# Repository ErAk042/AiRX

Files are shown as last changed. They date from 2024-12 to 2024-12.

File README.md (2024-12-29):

# AiRX
AiRX is a modularized fully-analog superheterodyne AM radio receiver for the aviation band (117-140MHz). The system consists of an input filter + LNA, a LNA + mixer stege for converting the band to 7-30MHz range, a Xtal oscillator at 110MHz as the first LO, and a LA1267 based AM radio to demodulate the signal with an additional LM386 amp for driving speakers.

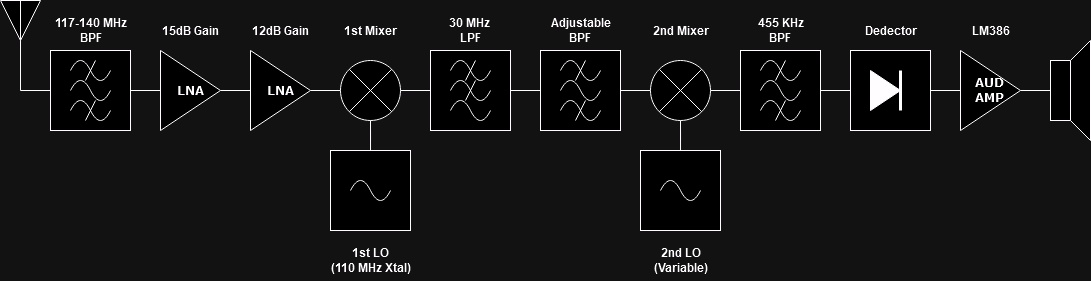
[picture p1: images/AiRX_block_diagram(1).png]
Block diagram of the overall system


## Input Stage
The input stage is a 9th order bandpass filter (117-40MHz passband) made using high-q aircore inductors. Right after the filter, there is a LNA block made using the BFP196W RF transistor. Bias network is made using a BC807 PNP transistor. The circuit aims to provide a 15mA current flow over the RF transistor. The overall gain of the LNA block here is around 15dB. The final PCB ins enclosed in a phosphorus-bronze enclosure and the power supply cable is filtered by going through a ferride bead to minimize the RF interference by nearby electronics.

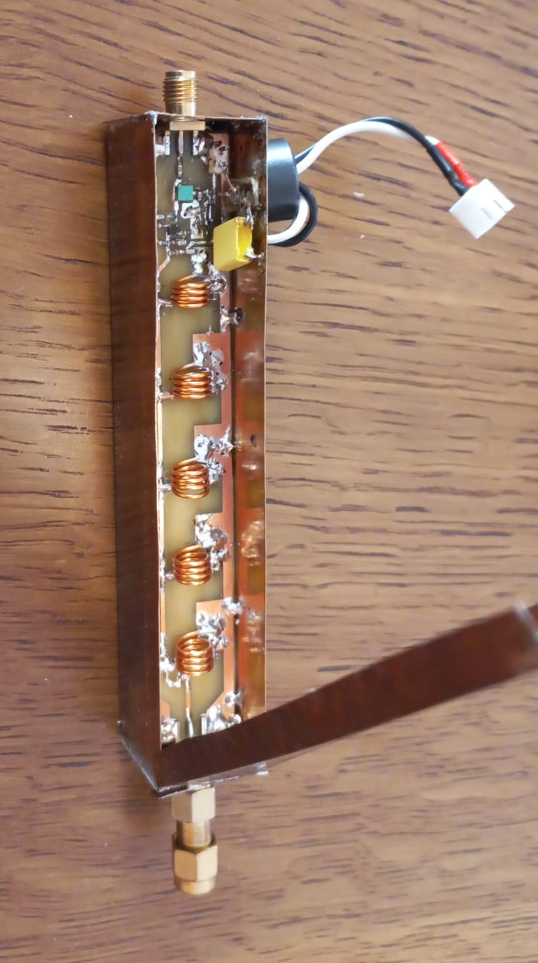
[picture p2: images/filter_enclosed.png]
The input stage inside it's enclosure. The sides of the lid are bent frequently with small cuts to improve the seal.

The input stage inside it's enclosure. The sides of the lid are bent frequently with small cuts to improve the seal.

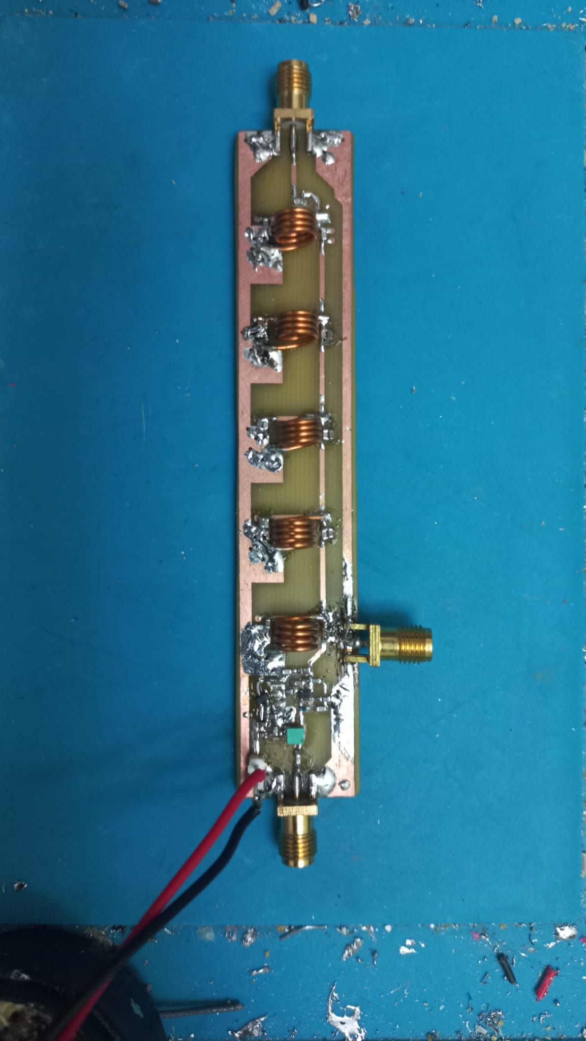
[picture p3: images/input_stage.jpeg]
The populated PCB of the input stage. The 3rd SMA connector on the long edge was a temporary test point between the filter and LNA.

The populated PCB of the input stage. The 3rd SMA connector on the long edge was a temporary test point between the filter and LNA.

## 110MHz Oscillator
A 22MHz crystal is used in 5th overtone to achieve 110MHz 1st LO frequency. There is a filter at the output of the oscillator buffer to filter out any potential harmonics/noise.

## Mixer Stage
The mixer used to bring the band down to the HF range is a SA612 double balanced mixer. At the RF input there is another LNA based on the same BFP196W transistor. It's the same circuit as the input stage LNA, only difference being that the current going through the transistor is roughly 1.4x higher. After that, the signal is fed to the 612's RF input with a 4:1 balun. Since the input impedance of the 612 is around 2kOhms, this balun allows the output of the transistor to be matched better than a straight transmission line. Since the band used is pretty wide, a matching network was not a practical solution in this case.
The 110MHz is directly fed into the base of the internal oscillator transistor of the 612.
At the output, there is a LPF with a cutoff frequency of 30MHz. This both filters out the images and reduces the overall noise level of the system.

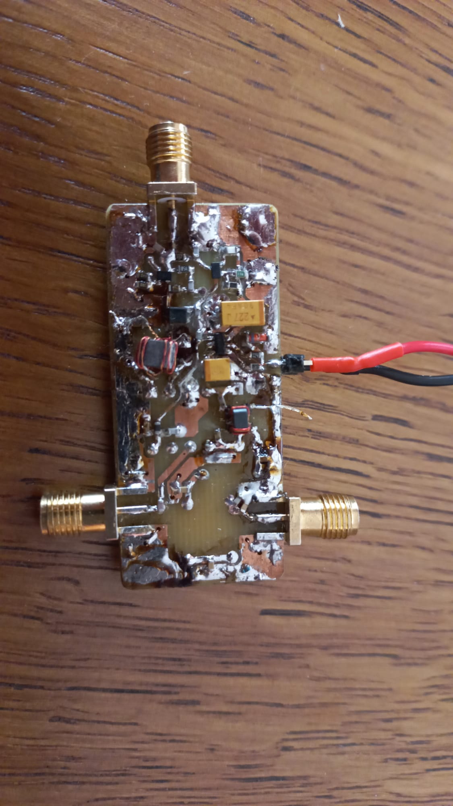
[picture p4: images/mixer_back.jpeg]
The back side of the mixer module.

The back side of the mixer module.

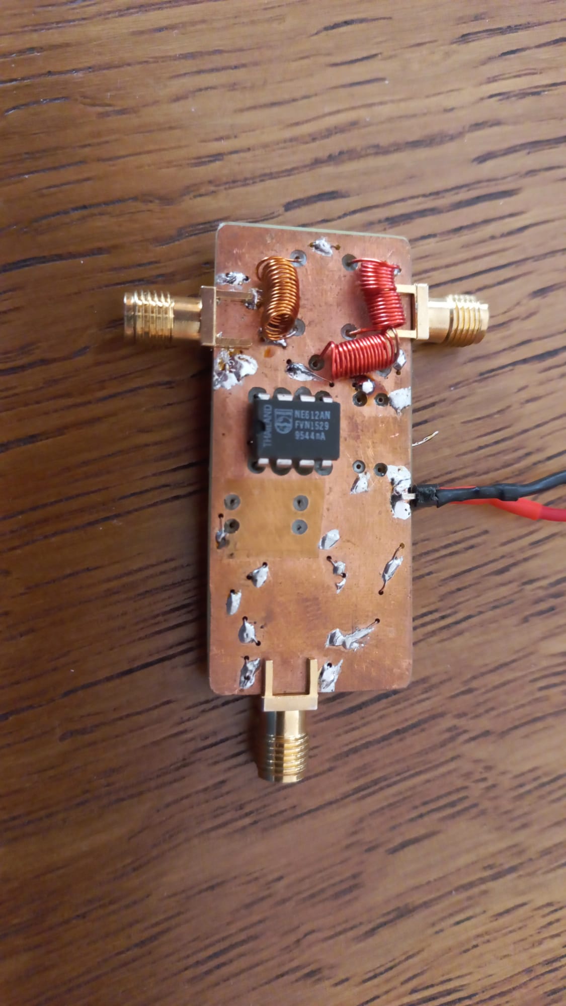
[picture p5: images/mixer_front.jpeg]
The front side of the mixer module.

The front side of the mixer module.

## AM Demodulator
The signals from the mixer module is directly fed to the input of this module. This is a superheterodyne shortwave radio based on the LA1267 chip by Sanyo. At the input, there is a variable band selective filter. The variable capacitor determines the band, as well as the LO frequency of the radio. The audio output is then fed into a LM386 amplifier. The outout can be directly used to drive medium-sized speakers. For the sake of conveniency, I later used a Si5351 frequency sythesizer controlled by an Arduino as the LO to precisely select the band that I wanted to listen to. I was able to account for the slight offset(24KHz) of the 110MHz oscillator with this solution, while achieving precise frequency control. This was a huge improvement since the bandwith is limited to 6-8KHz, which makes it hard to manually adjust the frequency using the variable capacitor without any pulley system. 

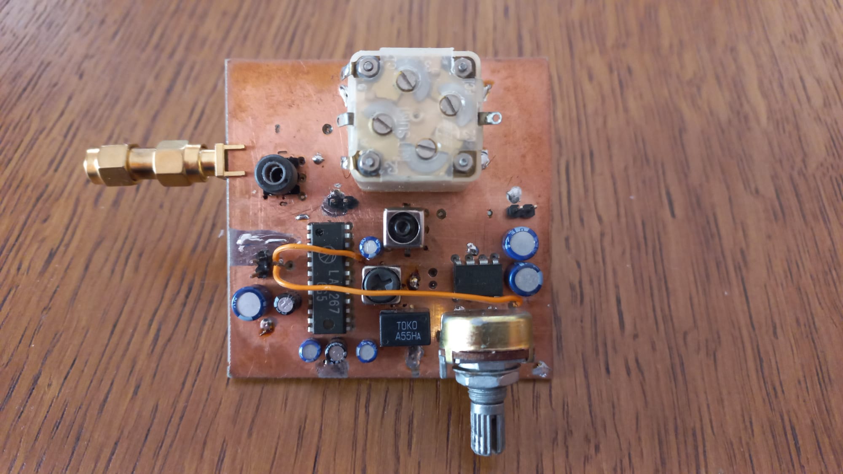
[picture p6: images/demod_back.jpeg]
The back side of the demodulator module.

The back side of the demodulator module.

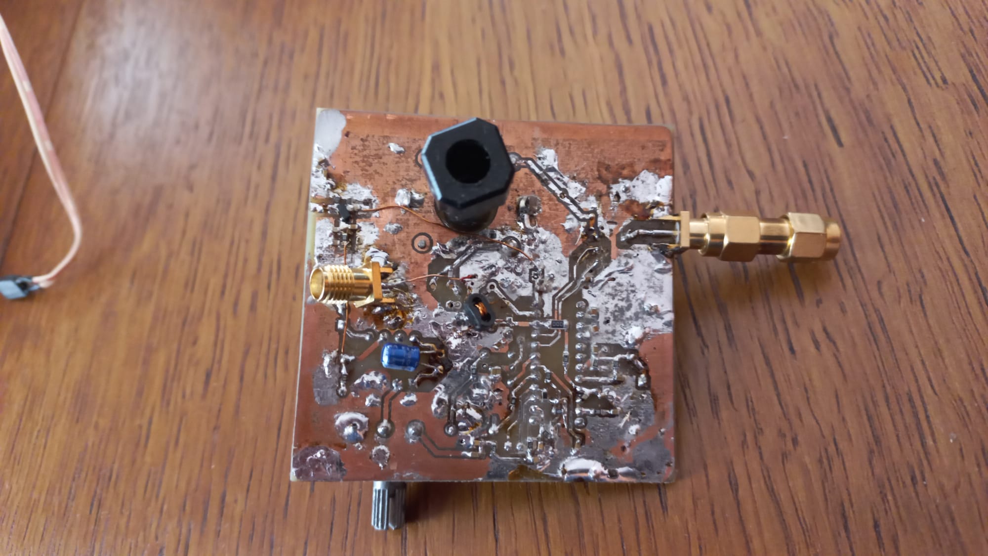
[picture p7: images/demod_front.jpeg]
The front side of the demodulator module.

The front side of the demodulator module.

## Planned future updates
I'm palnning on using a variable frequency filter for the input stage, which shoould help with the overall sensetivity of the system by limiting the witdh of the band admitted. Also, I want to use a more powerful mixer for the fisr mixer stage, so the dynamic range of the system can be improved. An AGC system is also within my plans.

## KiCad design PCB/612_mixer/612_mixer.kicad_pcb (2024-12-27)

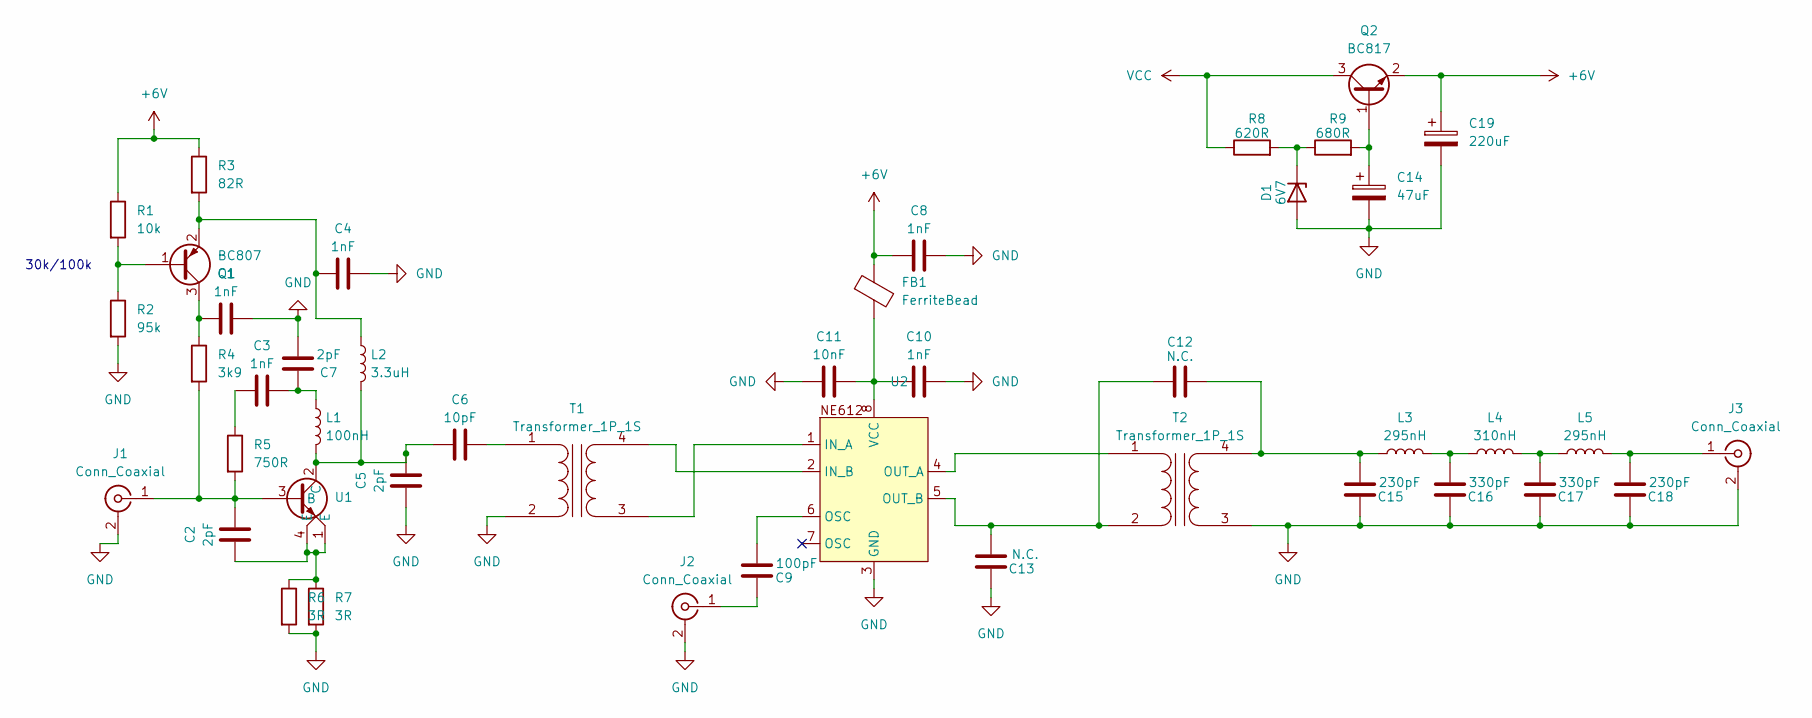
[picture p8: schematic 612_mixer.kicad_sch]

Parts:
C1, C3, C4, C8, C10: 1nF; C_0603_1608Metric
C2, C5, C7: 2pF; C_0603_1608Metric
C6: 10pF; C_0603_1608Metric
C9: 100pF; C_0603_1608Metric
C11: 10nF; C_0603_1608Metric
C12, C13: N.C.; C_0603_1608Metric
C14: 47uF; CP_EIA-3528-21_Kemet-B
C15, C18: 230pF; C_0603_1608Metric
C16, C17: 330pF; C_0603_1608Metric
C19: 220uF; CP_EIA-6032-28_Kemet-C
D1: 6V7; L_1206_3216Metric
FB1: FerriteBead; C_0603_1608Metric
J1, J2, J3: Conn_Coaxial; SMA_Samtec_SMA-J-P-H-ST-EM1_EdgeMount
L1: 100nH; L_0402_1005Metric
L2: 3.3uH; L_1008_2520Metric
L3, L5: 295nH; R_Axial_DIN0207_L6.3mm_D2.5mm_P7.62mm_Horizontal
L4: 310nH; R_Axial_DIN0207_L6.3mm_D2.5mm_P7.62mm_Horizontal
Q1: BC807; SOT-323_SC-70
Q2: BC817; SOT-23
R1: 10k; R_0603_1608Metric
R2: 95k; R_0603_1608Metric
R3: 82R; R_0603_1608Metric
R4: 3k9; R_0603_1608Metric
R5: 750R; R_0603_1608Metric
R6, R7: 3R; R_0603_1608Metric
R8: 620R; R_0603_1608Metric
R9: 680R; R_0603_1608Metric
T1, T2: Transformer_1P_1S; SW_DIP_SPSTx02_Slide_6.7x6.64mm_W7.62mm_P2.54mm_LowProfile
U1: SOT343_Transistor
U2: DIP-8_W7.62mm

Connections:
+6V: C8.2, C19.1, FB1.1, Q2.2 (E), R1.1, R3.1
GND: C1.1, C4.1, C5.2, C7.2, C8.1, C10.1, C11.1, C13.1, C14.2, C15.1, C16.1, C17.1, C18.1, C19.2, D1.2 (A), J1.2 (Ext), J2.2 (Ext), J3.2 (Ext), R2.2, R6.2, R7.2, T1.2 (AB), T2.3 (SA), U2.3 (GND)
unnamed: C2.2, R6.1, R7.1, U1.1 (E), U1.4 (E)
unnamed: C3.1, C7.1, L1.1
unnamed: C3.2, R5.1
unnamed: C9.2, U2.6 (OSC)
unnamed: C16.2, L3.2, L4.1
unnamed: C17.2, L4.2, L5.1
unnamed: D1.1 (K), R8.2, R9.1
unnamed: C2.1, J1.1 (In), R4.2, R5.2, U1.3 (B)
unnamed: C9.1, J2.1 (In)
unnamed: C18.2, J3.1 (In), L5.2
unnamed: Q1.1 (B), R1.2, R2.1
unnamed: C1.2, Q1.3 (C), R4.1
unnamed: C4.2, L2.1, Q1.2 (E), R3.2
unnamed: C14.1, Q2.1 (B), R9.2
unnamed: C6.1, T1.1 (AA)
unnamed: T1.3 (SA), U2.1 (IN_A)
unnamed: T1.4 (SB), U2.2 (IN_B)
unnamed: T2.1 (AA), U2.4 (OUT_A)
unnamed: C12.2, C13.2, T2.2 (AB), U2.5 (OUT_B)
unnamed: C12.1, C15.2, L3.1, T2.4 (SB)
unnamed: C5.1, C6.2, L1.2, L2.2, U1.2 (C)
unnamed: C10.2, C11.2, FB1.2, U2.8 (VCC)
VCC: Q2.3 (C), R8.1

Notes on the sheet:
30k/100k

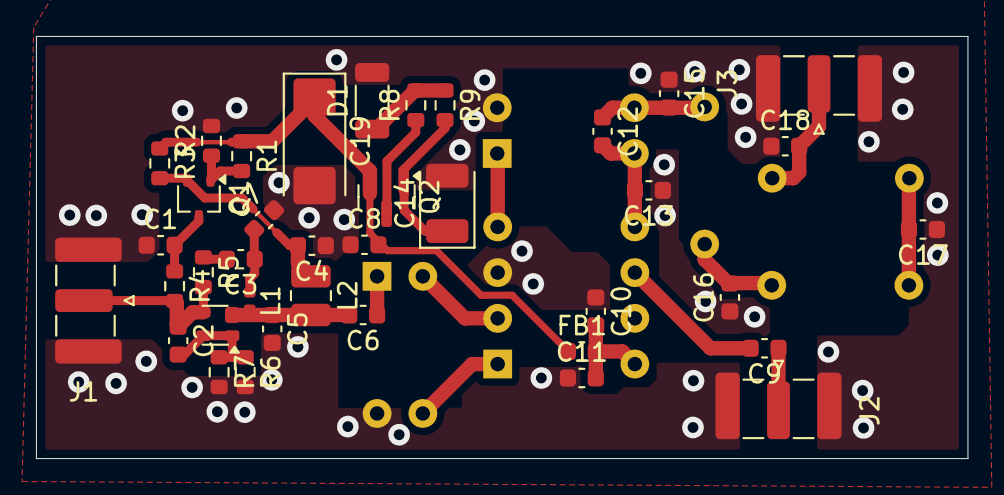
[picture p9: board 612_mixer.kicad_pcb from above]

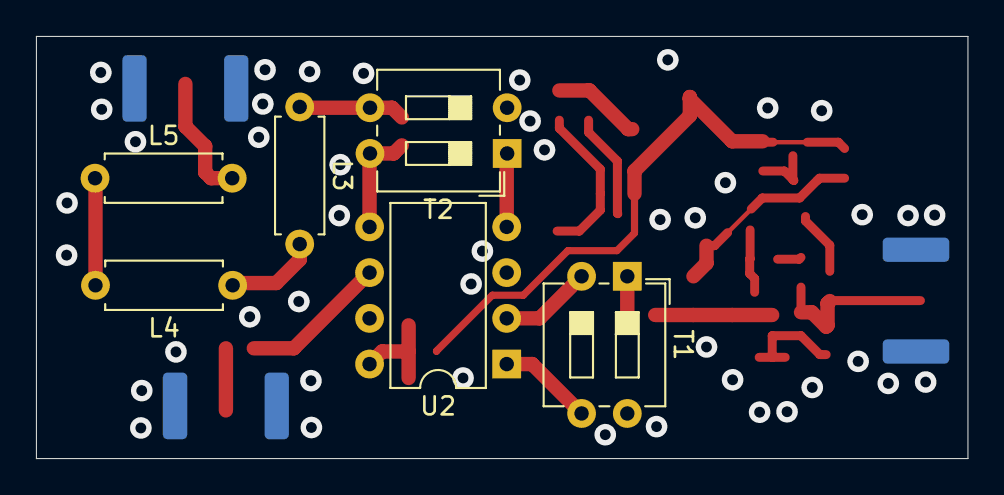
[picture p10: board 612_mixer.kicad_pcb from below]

Board: 2 copper layers, 51.8 x 23.5 mm, 44 parts (6 on the bottom side), 25 nets.

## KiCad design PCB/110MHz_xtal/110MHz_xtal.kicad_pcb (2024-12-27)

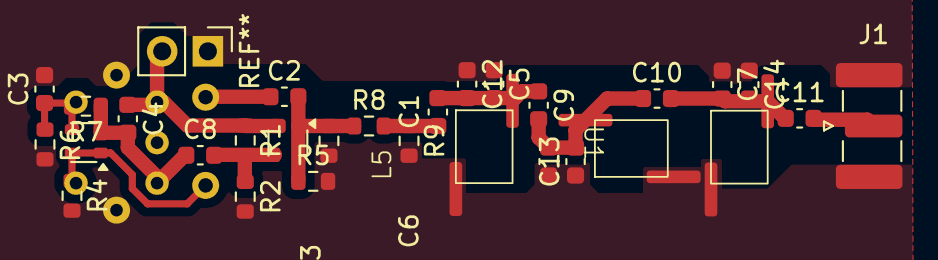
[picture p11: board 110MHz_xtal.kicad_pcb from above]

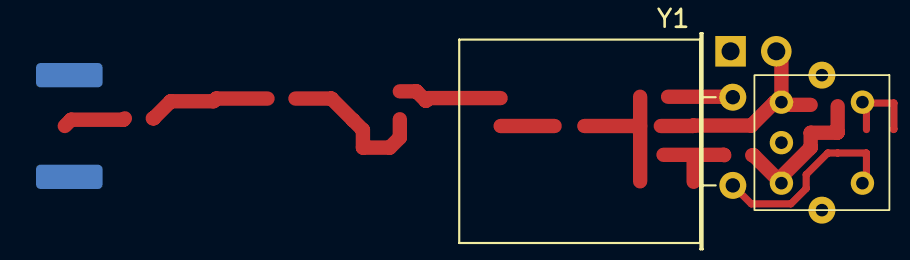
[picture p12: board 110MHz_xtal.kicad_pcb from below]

Board: 2 copper layers, 31 parts (2 on the bottom side), 13 nets.

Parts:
C1, C11: 2.9pF; C_0603_1608Metric
C2: 15pF; C_0603_1608Metric
C3, C4, C8: 1nF; C_0603_1608Metric
C5, C12: 17.67pF; C_0603_1608Metric
C6, C13: 20.12pF; C_0603_1608Metric
C7, C14: 17.62pF; C_0603_1608Metric
C9, C10: 0.5pF; C_0603_1608Metric
J1: Conn_Coaxial_Small; SMA_Samtec_SMA-J-P-H-ST-EM1_EdgeMount
L1: Inductor_IF
L4, L5, L6: L; inductor_small
R1: 51k; R_0603_1608Metric
R2, R6: N.C.; R_0603_1608Metric
R3, R8, R9: 15k; R_0603_1608Metric
R4: 330R; R_0603_1608Metric
R5: 150R; R_0603_1608Metric
R7: 470k; R_0603_1608Metric
U1, U2: SOT343_Transistor
Y1: Crystal; Crystal_HC49-U_Horizontal

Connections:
+BATT: C4.1, L1.1, R1.1, U1.2 (C)
GND: C3.2, C5.1, C6.1, C7.1, C12.1, C13.1, C14.1, J1.2 (Ext), L1.6, L4.1, L5.1, L6.1, R2.2, R3.2, R4.2, R5.2, R6.2, R9.2
unnamed: C1.1, R8.2, R9.1
unnamed: C1.2, C5.2, C9.1, C12.2, L4.2
unnamed: C2.1, Y1.1
unnamed: C2.2, R3.1, R5.1, R8.1, U1.1 (E), U1.4 (E)
unnamed: C6.2, C9.2, C10.1, C13.2, L5.2
unnamed: C7.2, C10.2, C11.1, C14.2, L6.2
unnamed: C11.2, J1.1 (In)
unnamed: L1.4, R4.1, U2.1 (E), U2.4 (E), Y1.2
unnamed: C8.2, R1.2, R2.1, U1.3 (B)
unnamed: C3.1, L1.5, R6.1, R7.2, U2.3 (B)
unnamed: C4.2, C8.1, L1.3, R7.1, U2.2 (C)

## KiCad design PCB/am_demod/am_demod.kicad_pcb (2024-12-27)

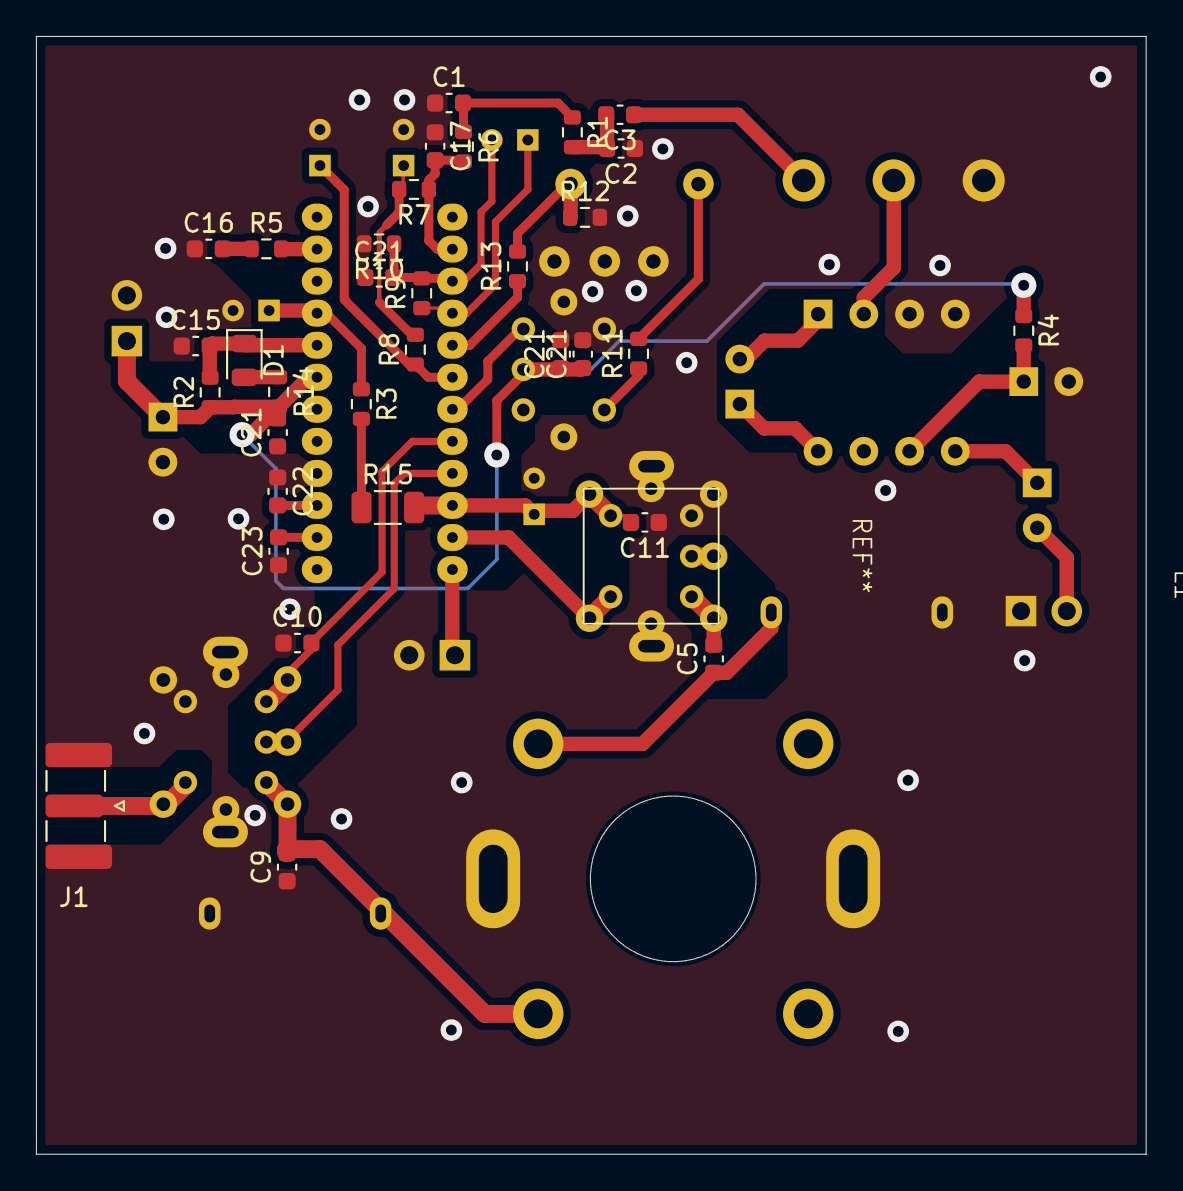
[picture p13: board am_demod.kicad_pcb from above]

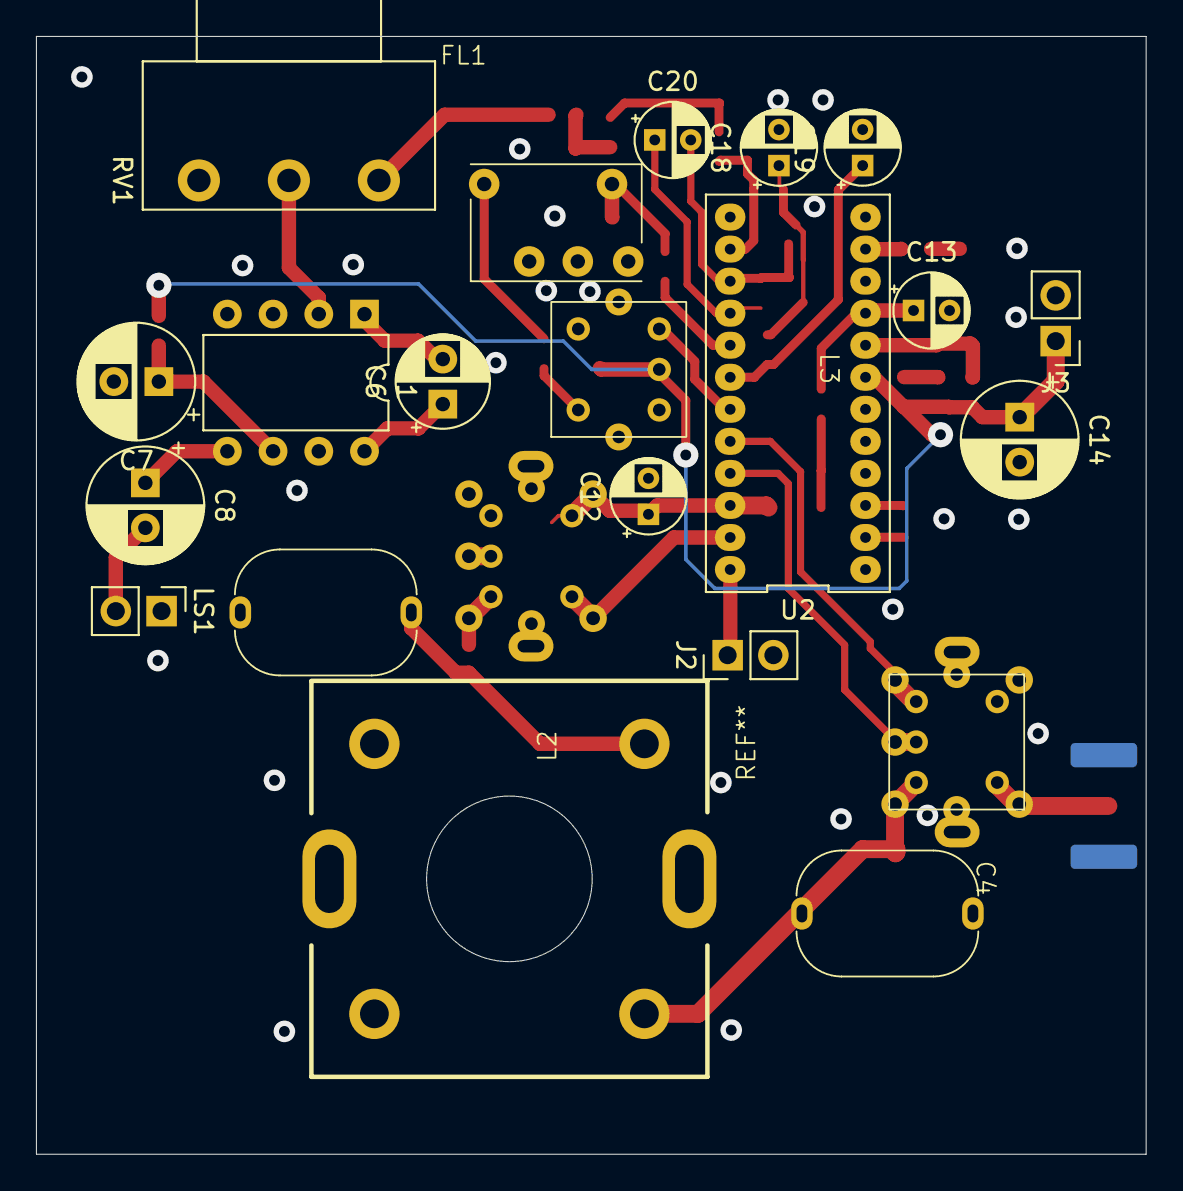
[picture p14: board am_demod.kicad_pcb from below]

Board: 2 copper layers, 61.7 x 62.1 mm, 55 parts (22 on the bottom side), 38 nets.

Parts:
C1: 10nF; C_0603_1608Metric
C2: 3.3nF; C_0603_1608Metric
C3: 100nF; C_0603_1608Metric
C4: Variable_Capacitance
C5: 4.7nF; C_0603_1608Metric
C6: 10uF; CP_Radial_D5.0mm_P2.50mm
C7: 100uF; CP_Radial_D6.3mm_P2.50mm
C8: 47uF; CP_Radial_D6.3mm_P2.50mm
C9: 15pF; C_0603_1608Metric
C10, C11, C15, C16, C22, C23: 47n; C_0603_1608Metric
C12, C13, C20: 10µF; CP_Radial_D4.0mm_P2.00mm
C14: 100µF; CP_Radial_D6.3mm_P2.50mm
C17: 15n; C_0603_1608Metric
C18: 3,3µF; CP_Radial_D4.0mm_P2.00mm
C19: 4,7µF; CP_Radial_D4.0mm_P2.00mm
C21, C21#2, C21#3, C21#4: 22nF; C_0603_1608Metric
C24, C25: C_Trim; cap_trim
D1: LED; LED_0805_2012Metric
FL1: A55Ha
J1: Conn_Coaxial; SMA_Samtec_SMA-J-P-H-ST-EM1_EdgeMount
J2, J3: Conn_01x02_Pin; PinHeader_1x02_P2.54mm_Vertical
L1, L2: if_inductor_am
L3: Inductor_IF
LS1: Speaker; PinHeader_1x02_P2.54mm_Vertical
R1: 2K7; R_0603_1608Metric
R2: 1k; R_0603_1608Metric
R3, R5, R14: 15k; R_0603_1608Metric
R4: 10R; R_0603_1608Metric
R6: 3k3; R_0603_1608Metric
R7, R8: 10k; R_0603_1608Metric
R9: 5k1; R_0603_1608Metric
R10: 12k; R_0603_1608Metric
R11, R12, R13: 0R; R_0603_1608Metric
R15: 0R; R_1206_3216Metric
RV1: 10K; Potentiometer_Piher_PC-16_Single_Horizontal
U1: LM386; DIP-8_W7.62mm
U2: DIP-24_296_ELL

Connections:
/AUD: C1.2, R1.1, R6.1
GND: C1.1, C2.1, C4.2, C4.5, C7.2, C9.1, C10.1, C11.1, C12.2, C13.2, C14.2, C15.1, C16.1, C17.1, C18.2, C19.2, C21.2, C21#2.1, C21#3.1, C21#4.2, C22.1, C23.1, C24.1, C25.1, FL1.3, FL1.4 (GND), FL1.5, J1.2 (Ext), J2.2, J3.2, L1.3, L1.6, L1.7, L2.5, L2.6, L2.7, L3.4, L3.6, LS1.1, R10.2, R12.2, RV1.3, U1.3 (+), U1.4 (GND), U2.4 (GND)
unnamed: C2.2, C3.2, R1.2
unnamed: C3.1, RV1.1
unnamed: C5.2, L1.1
unnamed: C6.1, U1.8 (GAIN)
unnamed: C6.2, U1.1 (GAIN)
unnamed: C8.1, U1.5
unnamed: C8.2, LS1.2
unnamed: C10.2, L2.3, U2.20 (AM_IN)
unnamed: C16.2, R5.1
unnamed: C18.1, R7.2, R8.2
unnamed: C20.1, R9.1, U2.16
unnamed: C20.2, C21#3.2, R9.2, R10.1, U2.15
unnamed: C22.2, U2.3
unnamed: C23.2, U2.2
unnamed: C4.4, C9.2, C24.2, L2.1
unnamed: C4.6, C5.1, C25.2
unnamed: D1.2 (A), R14.1
unnamed: C15.2, D1.1 (K), R2.2, U2.8 (LED_IN)
unnamed: FL1.1 (IN), R11.2
unnamed: FL1.2 (OUT), R12.1, R13.2
unnamed: J1.1 (In), L2.4
unnamed: J2.1, U2.24 (OSC_BUF)
unnamed: L2.2, U2.21 (AM_IN)
unnamed: L3.5, R11.1
unnamed: R3.2, R15.1
unnamed: RV1.2, U1.2 (-)
unnamed: C7.1, R4.2, U1.6 (V+)
unnamed: C19.1, R8.1, U2.18 (AGC)
unnamed: R13.1, U2.17 (AIF_IN)
unnamed: L3.3, U2.19 (AMIX_OUT)
unnamed: L1.4, U2.23 (AM_OSC)
unnamed: C17.2, R6.2, R7.1, U2.14 (AM_OUT)
unnamed: C11.2, C12.1, L1.5, R15.2, U2.22 (REG_OUT)
unnamed: C13.1, R3.1, U2.9 (S_CRV)
unnamed: R5.2, U2.11 (S_MET)
VCC: C14.1, C21.1, C21#2.2, C21#4.1, J3.1, L3.2, R2.1, R4.1, R14.2, U2.7 (VCC)

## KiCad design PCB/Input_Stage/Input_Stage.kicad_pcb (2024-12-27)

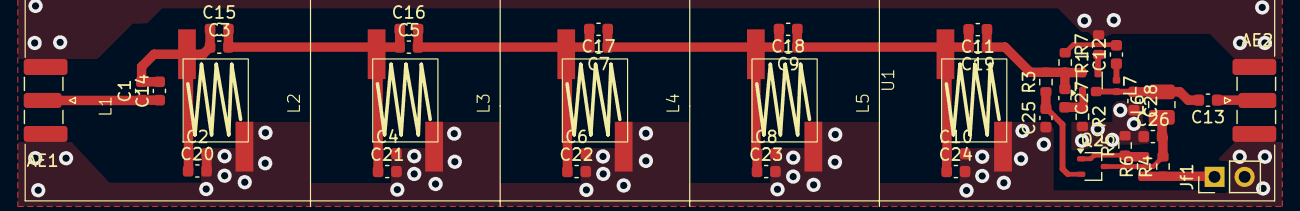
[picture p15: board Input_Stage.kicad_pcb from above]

Board: 2 copper layers, 47 parts (0 on the bottom side), 17 nets.

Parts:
AE1, AE2: Antenna; SMA_Samtec_SMA-J-P-H-ST-EM1_EdgeMount
C1, C11, C13, C14, C19: 10pF; C_0603_1608Metric
C2, C10, C20, C24: 12pF; C_0603_1608Metric
C3, C9, C15, C18: 2.7pF; C_0603_1608Metric
C4, C6, C8, C21, C22, C23: 15pF; C_0603_1608Metric
C5, C7, C16, C17: 1.8pF; C_0603_1608Metric
C12, C25, C26: 1nF; C_0603_1608Metric
C27, C28: 2pF; C_0603_1608Metric
Jf1: Conn_01x02_Pin; PinHeader_1x02_P2.54mm_Vertical
L1, L2, L3, L4, L5: 3.3uH; Inductor_Aircore
L6: 3.3uH; L_1008_2520Metric
L7: 100nH; L_0402_1005Metric
Q2: BC807; SOT-323_SC-70
R1: 750R; R_0603_1608Metric
R2, R7: 3R; R_0603_1608Metric
R3: 3k9; R_0603_1608Metric
R4: 82R; R_0603_1608Metric
R5: 95k; R_0603_1608Metric
R6: 10k; R_0603_1608Metric
U1: SOT343_Transistor

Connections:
+BATT: Jf1.1, R4.1, R6.1
GND: AE1.2, AE2.2, C2.2, C4.2, C6.2, C8.2, C10.2, C20.2, C21.2, C22.2, C23.2, C24.2, C25.1, C26.1, C28.2, Jf1.2, L1.2, L2.2, L3.2, L4.2, L5.2, R2.2, R5.2, R7.2
unnamed: AE1.1 (A), C1.1, C14.1
unnamed: AE2.1 (A), C13.1
unnamed: C1.2, C2.1, C3.1, C14.2, C15.1, C20.1, L1.1
unnamed: C9.1, C10.1, C11.2, C18.1, C19.2, C24.1, L5.1
unnamed: C12.1, L7.1
unnamed: C12.2, R1.1
unnamed: C3.2, C4.1, C5.1, C15.2, C16.1, C21.1, L2.1
unnamed: C5.2, C6.1, C7.2, C16.2, C17.2, C22.1, L3.1
unnamed: C7.1, C8.1, C9.2, C17.1, C18.2, C23.1, L4.1
unnamed: C27.2, R2.1, R7.1, U1.1 (E), U1.3 (E)
unnamed: Q2.1 (B), R5.1, R6.2
unnamed: C26.2, L6.1, Q2.3 (C), R4.2
unnamed: C25.2, Q2.2 (E), R3.1
unnamed: C11.1, C19.1, C27.1, R1.2, R3.2, U1.4 (B)
unnamed: C13.2, C28.1, L6.2, L7.2, U1.2 (C)
